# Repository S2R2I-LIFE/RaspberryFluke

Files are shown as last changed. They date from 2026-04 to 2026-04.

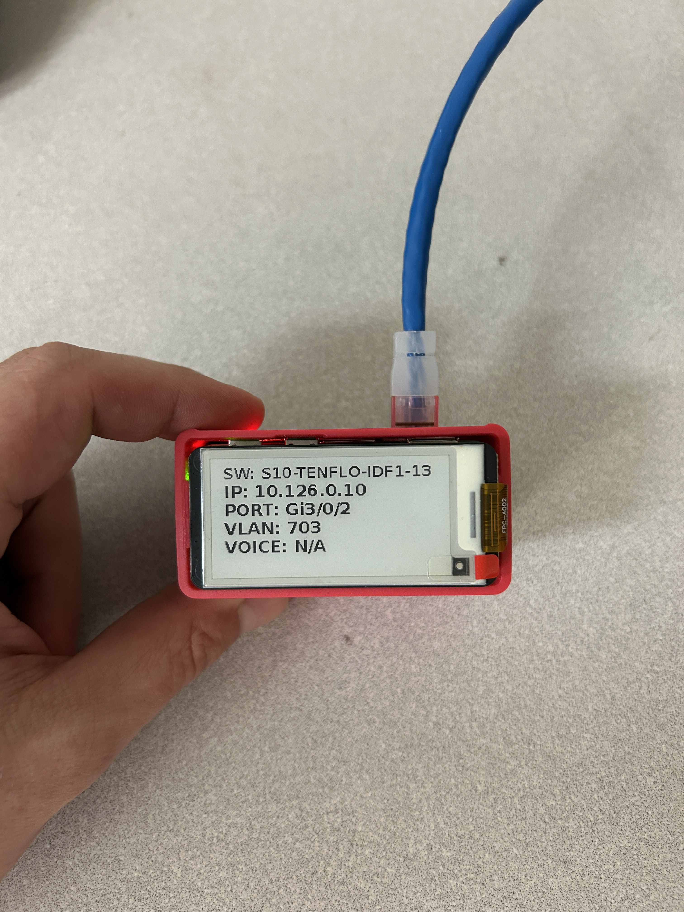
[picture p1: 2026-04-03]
Device_Top_Down_Fully_Assembled.JPG

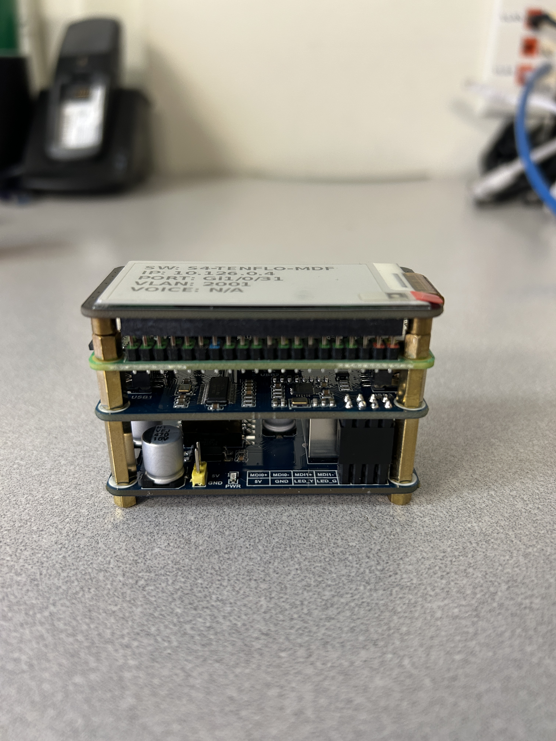
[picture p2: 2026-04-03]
Device_Frontside_No_Case.JPG

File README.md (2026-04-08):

---

# RaspberryFluke

Pocket network diagnostic tool that displays LLDP/CDP switch data using a Raspberry Pi Zero 2 W, a PoE HAT, and an E-Paper display.

Inspired by the functionality of commercial network port identification tools used by field technicians.

---

## Overview

This project is a pocket-sized network diagnostic tool designed to quickly identify switch port information such as hostname, IP address, port number, VLAN, and voice VLAN using LLDP/CDP.  

The device runs on a Raspberry Pi Zero 2 W and displays results on an e-Paper display, making it useful for technicians deploying or troubleshooting network equipment in the field.

This variation of the project has been refined for Juniper and Arista Networking devices while also including the original CDP capabilities.

---

## Why This Exists

Commercial network diagnostic tools that provide quick switch port identification can be expensive. This project explores how a small Linux-based device can extract useful switch information using LLDP/CDP and display it on a low-power screen.

The goal was to build a simple, practical tool using inexpensive and widely available hardware.

---

## Features

- Runs on Raspberry Pi Zero 2 W
- Low power E-Paper display
- Fast boot and automatic detection
- Powered by PoE via a PoE HAT or a USB power bank

---
  
### Currently Displays

- Hostname
- IP Address
- Identifies switch port, port speed (hidden unless available) and PoE
- Description (if any)
- Displays Access VLAN & Voice VLAN
- Model information
- OS version number

---

### Display Output

```text
SW: SWITCH-01  
IP: 10.10.1.2  
P: ge-1/0/24 | 13W
D: Description on port 
VLAN: 120  V-V: 130
M: ex2300-c-12p
OS: JUNOS 21.4R3-S2.4
```

---

## Hardware

- Raspberry Pi Zero 2 W
- 40-pin male GPIO Header
- Waveshare PoE Ethernet / USB HUB BOX (SKU 20895)
- Tested displays:
    - Waveshare 2.13" E-Paper HAT+ display (SKU 27467)
    - Waveshare 2.13" E-Paper HAT (B), 250x122, Red/Black/White, SPI (SKU 13448)

---

## Software

- Raspberry Pi OS
- Python
- LLDP/CDP parsing
- Waveshare EPD drivers
- systemd service for automatic startup

---

## How It Works

Connect the device to an Ethernet cable connected to an active switch.

If PoE is enabled on the port, the device powers on automatically. If PoE is not available, the device can be powered using an external power source such as a USB power bank.

Once powered on, the Raspberry Pi boots into Raspberry Pi OS. A systemd service automatically launches the Python script which listens for LLDP/CDP packets transmitted by the switch.

The script extracts relevant switch information such as hostname, IP address, port number, VLAN, and voice VLAN. The data is then formatted and displayed on the e-Paper screen. 

---

## Installation

1. Flash Raspberry Pi OS to the SD card using Raspberry Pi Imager.

2. Boot the Raspberry Pi and update the system:

```bash
sudo apt update
sudo apt upgrade -y
```

3. Install required packages:

```bash
sudo apt -y install git lldpd python3 python3-pip python3-pil python3-lgpio python3-rpi.gpio
```

4. Enable SPI (required for the E-Paper display):

```bash
sudo raspi-config
```

Navigate to:
Interface Options -> SPI -> Enable

5. Reboot the device

```bash
sudo reboot
```

6. Configure lldpd for CDP and receive-only mode:

```bash
sudo nano /etc/default/lldpd
```
Set:

```ini
DAEMON_ARGS="-r -c"
LLDPD_OPTIONS=""
```

7. Restart lldpd:

```bash
sudo systemctl restart lldpd
```

8. Clone the RaspberryFluke repository into /opt:

```bash
sudo rm -rf /opt/raspberryfluke
sudo git clone https://github.com/S2R2I-LIFE/RaspberryFluke.git /opt/raspberryfluke
sudo chown -R root:root /opt/raspberryfluke
```

**Important** - If you are using the E-Paper HAT+ with the Black and White display you will need to run this: 

```bash
sudo cp /opt/raspberryfluke/raspberryfluke.py /opt/raspberryfluke/raspberryfluke_rw&b.py
sudo cp /opt/raspberryfluke/raspberryfluke_b&w.py /opt/raspberryfluke/raspberryfluke.py
```

This just copies the current .py file made for the Red, White and Black display and replaces it with the Black and White version.
The screens **will** share driver functionality although the color display does not support partial refresh leading to potential damage to the screen.

9. Clone the Waveshare repository:

```bash
cd ~
git clone https://github.com/waveshare/e-Paper.git
```

10. Copy the waveshare_epd library into /opt/raspberryfluke:

```bash
sudo cp -r ~/e-Paper/RaspberryPi_JetsonNano/python/lib/waveshare_epd /opt/raspberryfluke/
```

11. Make the script executable:

```bash
sudo chmod 755 /opt/raspberryfluke/raspberryfluke.py
```

12. Install the System Service File

```bash
sudo cp /opt/raspberryfluke/raspberryfluke.service /etc/systemd/system/
```

13. Enable and start the service:

```bash
sudo systemctl daemon-reload
sudo systemctl enable raspberryfluke.service
sudo systemctl start raspberryfluke.service
```

14. Verify the service is running:

```bash
sudo systemctl status raspberryfluke.service
```

The RaspberryFluke script will now run automatically each time the device boots.

---

## EXTRA

If the last status check throws an error and you are using the latest RaspberryPiOS-Lite x64 you may need the default font packages for the ePaper display to work properly.

```bash
sudo apt install fonts-dejavu fonts-liberation fonts-freefont-ttf -y
```

---

## Even Lighter

Make the PiOS-Lite a bit quicker to boot

```bash
sudo nano /boot/firmware/config.txt
```
Disable Audio, Disable Bluetooth (if you only use SSH over WiFi/Ethernet), Give minimum RAM to the GPU (you don't need a GPU for SPI e-paper)
```text
dtparam=audio=off
dtoverlay=disable-bt
gpu_mem=16
```
Disable background services (few may not be running but try anyway)
```bash
sudo systemctl disable triggerhappy.service
sudo systemctl disable avahi-daemon.service
sudo systemctl disable bluetooth.service
sudo systemctl disable hciuart.service
sudo systemctl disable keyboard-setup.service
```

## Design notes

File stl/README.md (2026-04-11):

# Pi-Fluke Case Lid

A custom 3D-printed lid and bezel designed to turn a Raspberry Pi Zero into a sleek, professional, PoE-powered network discovery tool (LLDP/CDP). 

This model is designed to act as a replacement lid that seamlessly integrates with the factory bottom casing provided in the **Waveshare Pi Zero PoE HAT** kit. When paired with a Waveshare 2.13" e-Paper display, it creates a rugged, pocket-sized tester perfect for network engineers and IT professionals.

## ✨ Design Features
* **Perfect Fit:** Features beveled edging designed to snap directly into the original plastic bottom casing that comes with the Waveshare PoE kit.
* **Port Clearances:** One side of the interior is specifically inset to compensate for the mini-HDMI and micro-USB power inputs on the Raspberry Pi Zero board, ensuring a flush fit without stressing the PCB.
* **Screen Framing:** Perfectly frames the 2.13" e-Paper display, hiding the ribbon cable and PCB bezels for a commercial-grade look.
* **Custom Branding:** Features a sleek "Pi-Fluke" inset text on the front bezel.

## 🖨️ Recommended Print Settings
This model was tested and optimized on a **Creality K1** using the **CFS (Creality Filament System)** for the multi-color text and two-tone aesthetic. You do not need a CFS to get the color for the lid if you are able to swap the filament it is only a single layer that gives it the pop color!

* **Printer Used:** Creality K1 with CFS upgrade
* **Nozzle Size:** 0.4 mm
* **Material:** PETG *(Highly recommended over PLA, as the PoE HAT and Pi Zero can generate warm temperatures during continuous use).*
* **Infill:** 15%
* **Supports:** No supports are required depending on your bridging capabilities for the lid clip housing or how you decide to print.

### 🎨 The Multi-Color / Border Slicer Trick
To achieve the exact text and inner screen border look seen in the photos, a specific layering trick was used:
* A single **0.2mm layer** was placed on the bottom of the inset for the "Pi-Fluke" text.
* Simply take the color tool and using a **0.4mm layer height line** cover that inset layer so that there is a single 0.4mm layer around the entire lid. 
* This technique covers the 0.2mm layer, resulting in a unique "mixed coloring" look for the top bezel, while leaving a perfectly defined text and accent stripe around the inside edge of the screen bezel!

## 🛠️ Hardware Used in this Build
To complete this build as pictured, you will need:
1. **Raspberry Pi Zero 2 W**
2. **Waveshare PoE/ETH USB HUB HAT** (specifically the kit that includes the white/black plastic bottom tub)
3. **Waveshare 2.13" e-Paper HAT** (V4 - Red/Black/White or Black/White)

## ⚙️ Assembly Notes
1. Assemble the Pi Zero and PoE HAT into the original Waveshare bottom case.
2. Attach the e-Paper display to the GPIO pins.
3. Gently press the 3D-printed Pi-Fluke lid over the top. Ensure the side with the internal inset is aligned with the Pi Zero's USB and HDMI ports so the board isn't pinched. 
4. The beveled edges should sit cleanly against the factory bottom case.

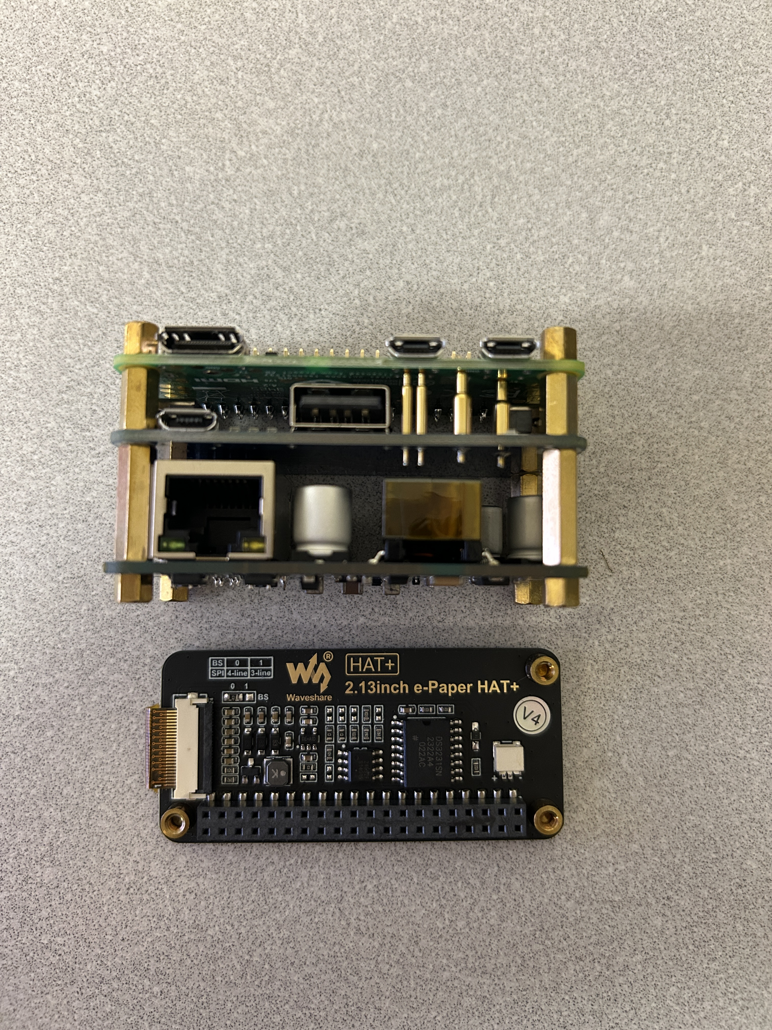
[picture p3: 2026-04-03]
Device_Frontside_Screen_Detached_No_Case.JPG

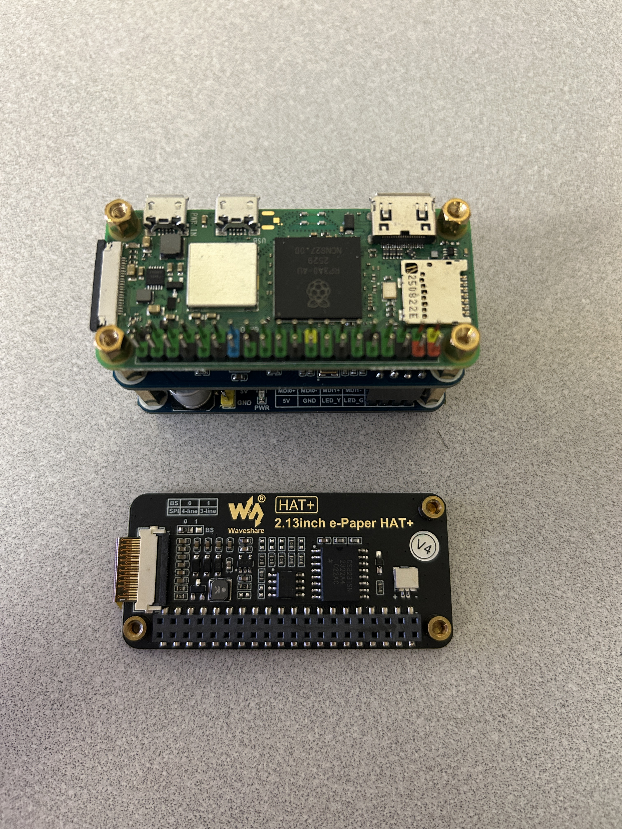
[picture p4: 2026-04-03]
Device_Top_Down_Screen_Detached_No_Case.JPG

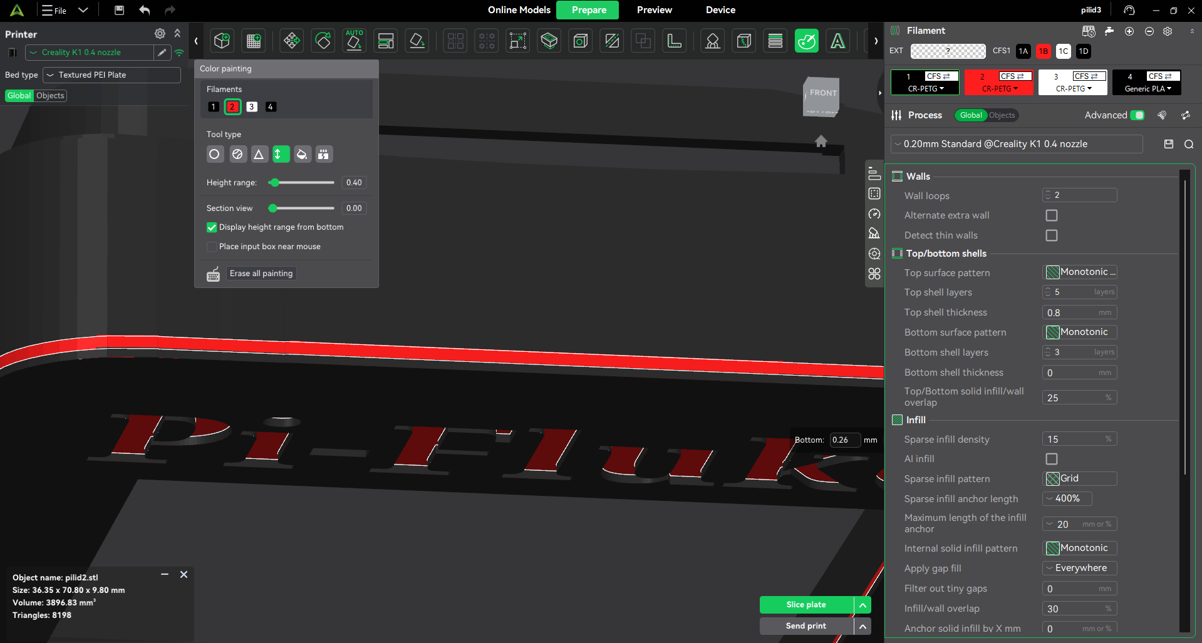
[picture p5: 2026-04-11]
stl/Layer line.png

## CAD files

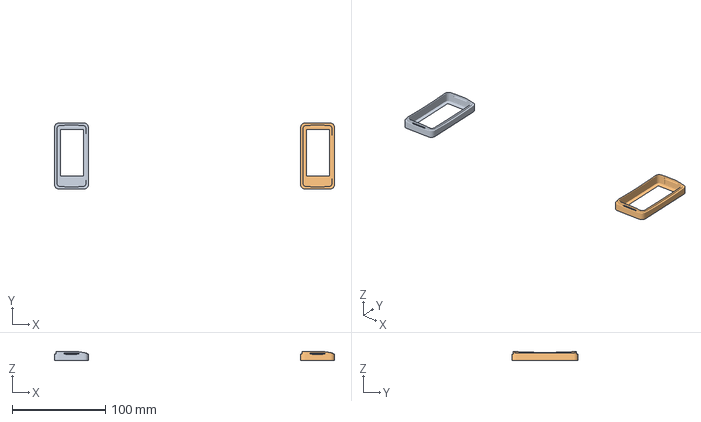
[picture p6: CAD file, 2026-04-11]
stl/pilid.3mf
300.3 x 70.8 x 9.80 mm
pilid2.stl x 2

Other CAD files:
stl/pilid.stl

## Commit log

2026-04-03 Added photos of the physical device
2026-04-10 Create raspberryfluke_RBW
